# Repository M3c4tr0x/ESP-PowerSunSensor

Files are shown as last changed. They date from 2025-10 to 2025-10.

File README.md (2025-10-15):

# Irradiance and Theoretical Power Calculation Board for Photovoltaic Systems

This board is designed to measure irradiance using a small solar panel and to estimate the theoretical power output of a photovoltaic installation using an NTC temperature sensor placed on one of the panels.

The system is intended for photovoltaic setups that **cannot inject electricity into the grid** — whether on-grid or off-grid. It helps determine real-time production capacity and supports better energy management and self-consumption.

## Features

- **Irradiance Measurement**  
  A miniature solar panel captures real-time irradiance levels.

- **Theoretical Power Estimation**  
  An NTC sensor measures panel temperature to calculate expected power output under current conditions.

- **No-Grid-Injection Systems**  
  Ideal for photovoltaic installations restricted from injecting power into the grid.

- **Performance Monitoring**  
  Provides data to evaluate the system's efficiency and optimize energy usage.
  
  On the first graphe below, you can see the values of the ESP-PowerSunSensor are shown in blue, and my solar production values in yellow :
  
  Capture d'écran 2025-10-09 132655

  Below is the list of the different data reported by the sensor : 
  
  Capture d'écran 2025-10-15 134230

## Use Cases

- Estimating maximum potential production of a solar installation  
- Monitoring performance over time  
- Supporting system design or troubleshooting  
- Managing loads in self-consumption scenarios

## Required Components

- Miniature solar panel (I personally used the glass solar panel from a solar garden lamp recovered from the recycling center)  
- NTC temperature sensor (attach to one of the main panels) : Any NTC sensor can be used, as long as you adapt the pull-up resistor (R16 on the PCB) value and know the sensor’s B25/50 characteristics, which should be entered into the YAML configuration.
- An ESP-PowerSunSensor PCB wired according to the associated schematic diagram
- Power supply and data interface (USB, Wi-Fi, etc.)

Beta version : 



## 💰 How Much Does It Cost?

This project is designed to be **as low-cost as possible**, using affordable or recycled components.

| Component | Estimated Price (€) | Notes |
|---|---|---|
| Miniature solar panel | 0 – 5 € | Recovered from a solar garden lamp (recycling center, old devices) |
| NTC temperature sensor | 1 – 3 € | Any NTC sensor works 10kR to 100kR (adapt pull-up resistor and B-value in YAML) |
| ESP32-C3-WROOM-02 | 3 – 8 € | |
| ESP-PowerSunSensor PCB | 2 – 5 € | Depending on quantity and supplier (JLCPCB, PCBWay, etc.) |
| Resistors, connectors, etc. | 1 – 2 € | Very cheap, or reusable from old electronics |
| 5V USB power supply | 2 – 5 € | Standard USB charger or reused power source |

### 💡 Total Estimated Cost: **around 10 to 25 €**

> 💬 **Tip**: If you recycle parts (panel, power supply, cables), the full setup can cost **less than 10 €**!

## Installation

1. Connect J2 by strapping it to enable bootloader mode on the ESP32
2. Attach the electronic board to your computer using an USB cable.
3. Disconnect J2 (unstrap it) after enabling bootloader mode
4. Go to your ESP-home server and flash the new device with attached yaml customized for your settings
5. After that, you can remove the USB cable
6. Connect the miniature solar panel to the input for irradiance measurement (J3).
7. Attach the NTC sensor firmly to the back side of one of your main solar panels and connect it on J1 connector.


8. Mount the sensor in same direction of your installation you want to monitor, example (files attached in repo) :





9. You can separate the solar panel and NTC sensor from the electronics PCB. In my case, they are positioned 15 meters apart, and the system works fine. This tip allows for a better Wi-Fi connection by placing the electronics closer to my Wi-Fi access point.
10. Connect the USB cable to the power supply.
11. Enjoy your setup and power monitoring!

## Author

- @M3c4tr0x

## License

[MIT License]

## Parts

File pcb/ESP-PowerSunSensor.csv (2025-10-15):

Reference | Qty | Value | DNP | Exclude from BOM | Exclude from Board | Footprint | Datasheet
C1 | 1 | 220nF |  |  |  | Capacitor_SMD:C_0603_1608Metric_Pad1.08x0.95mm_HandSolder | ~
C2,C3,C5 | 3 | 100nF |  |  |  | Capacitor_SMD:C_0603_1608Metric_Pad1.08x0.95mm_HandSolder | ~
C4,C6,C7 | 3 | 10uF |  |  |  | Capacitor_SMD:C_0603_1608Metric_Pad1.08x0.95mm_HandSolder | ~
D1,D2 | 2 | LED |  |  |  | LED_SMD:LED_0603_1608Metric_Pad1.05x0.95mm_HandSolder | ~
D6 | 1 | BAS516 |  |  |  | Diode_SMD:D_SOD-523 | https://assets.nexperia.com/documents/data-sheet/BAS16_SER.pdf
FID1,FID2,FID3,FID4 | 4 | Fiducial |  | Exclure de la Liste du Matériel |  | MountingHole:MountingHole_3.2mm_M3 | ~
J1,J2 | 2 | Conn_01x02_Pin |  |  |  | Connector_PinHeader_2.54mm:PinHeader_1x02_P2.54mm_Vertical | ~
J3 | 1 | Conn_01x02 |  |  |  | Connector_Phoenix_MSTB:PhoenixContact_MSTBVA_2,5_2-G-5,08_1x02_P5.08mm_Vertical | ~
J4 | 1 | Conn_01x04_Pin |  |  |  | Connector_PinHeader_2.54mm:PinHeader_1x04_P2.54mm_Vertical | ~
J5 | 1 | USB_C_Receptacle_USB2.0_16P |  |  |  | oem_connecteur:GCT_USB4500-03-0-A_REVA1 | https://www.usb.org/sites/default/files/documents/usb_type-c.zip
JP1,JP2 | 2 | SolderJumper_3_Open |  |  |  | Jumper:SolderJumper-3_P2.0mm_Open_TrianglePad1.0x1.5mm_NumberLabels | ~
R1 | 1 | R |  |  |  | Resistor_SMD:R_2512_6332Metric_Pad1.40x3.35mm_HandSolder | ~
R2,R3 | 2 | 10R |  |  |  | Resistor_SMD:R_0603_1608Metric_Pad0.98x0.95mm_HandSolder | ~
R4,R5,R6,R7,R8,R9 | 6 | 10k |  |  |  | Resistor_SMD:R_0603_1608Metric_Pad0.98x0.95mm_HandSolder | ~
R10,R11 | 2 | 0R |  |  |  | Resistor_SMD:R_0603_1608Metric_Pad0.98x0.95mm_HandSolder | ~
R12,R13 | 2 | 1k |  |  |  | Resistor_SMD:R_0603_1608Metric_Pad0.98x0.95mm_HandSolder | ~
R14,R15 | 2 | 5.1k |  |  |  | Resistor_SMD:R_0603_1608Metric_Pad0.98x0.95mm_HandSolder | ~
R16 | 1 | 12k |  |  |  | Resistor_SMD:R_0603_1608Metric_Pad0.98x0.95mm_HandSolder | ~
U1 | 1 | INA228 |  |  |  | Package_SO:VSSOP-10_3x3mm_P0.5mm | https://www.ti.com/lit/ds/symlink/ina228.pdf
U2 | 1 | ESP32-C3-WROOM-02 |  |  |  | RF_Module:ESP32-C3-WROOM-02 | https://www.espressif.com/sites/default/files/documentation/esp32-c3-wroom-02_datasheet_en.pdf
U4 | 1 | NCP1117-3.3_SOT223 |  |  |  | Package_TO_SOT_SMD:SOT-223-3_TabPin2 | http://www.onsemi.com/pub_link/Collateral/NCP1117-D.PDF

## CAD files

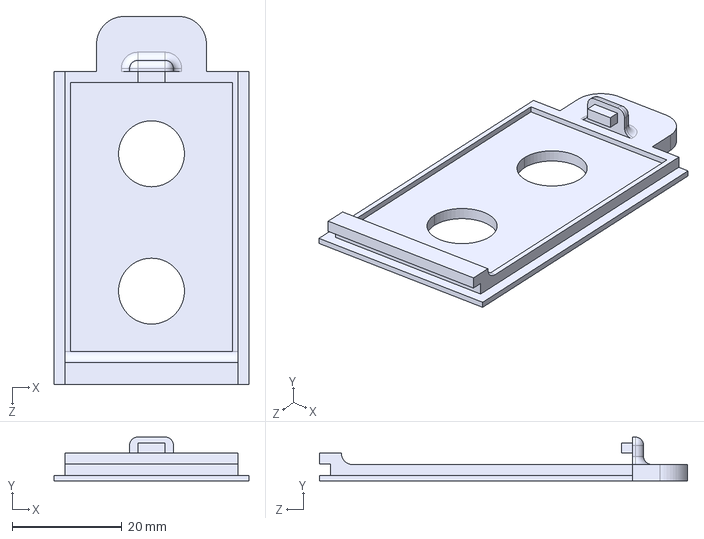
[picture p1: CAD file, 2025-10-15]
case/trappe de maintenance.STEP
35.5 x 8.00 x 67.0 mm

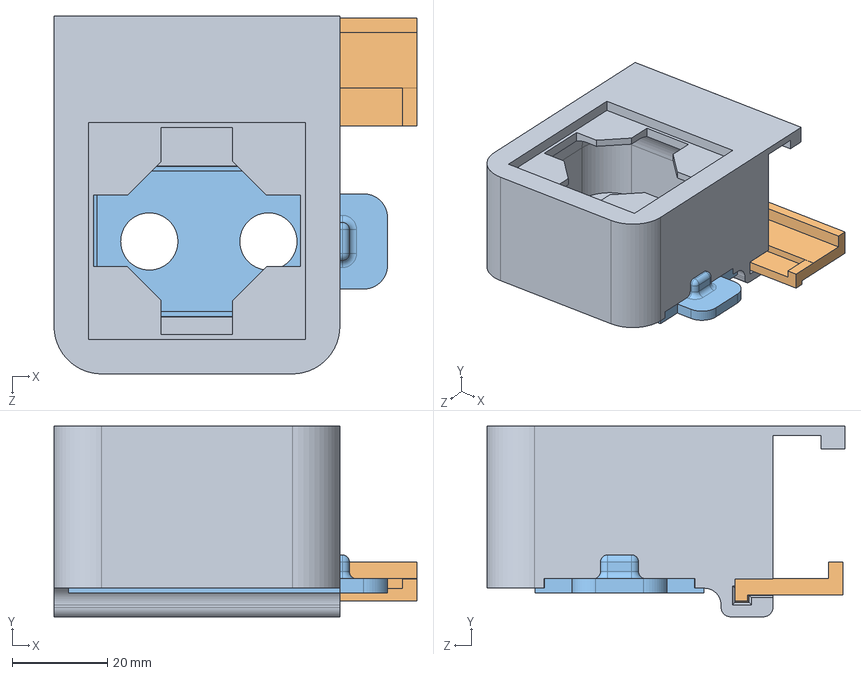
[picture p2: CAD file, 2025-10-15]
case/support capteur PV assemblé.STEP
76.2 x 40.0 x 75.1 mm
support capteur PV
clip support PV
trappe de maintenance

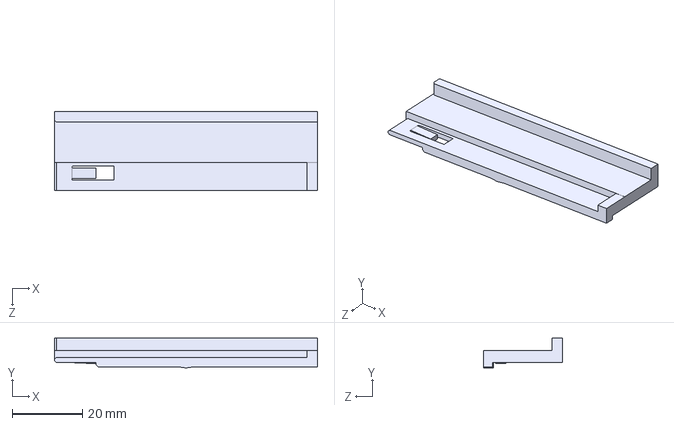
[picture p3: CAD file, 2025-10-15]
case/clip support PV.STEP
75.0 x 8.50 x 22.6 mm

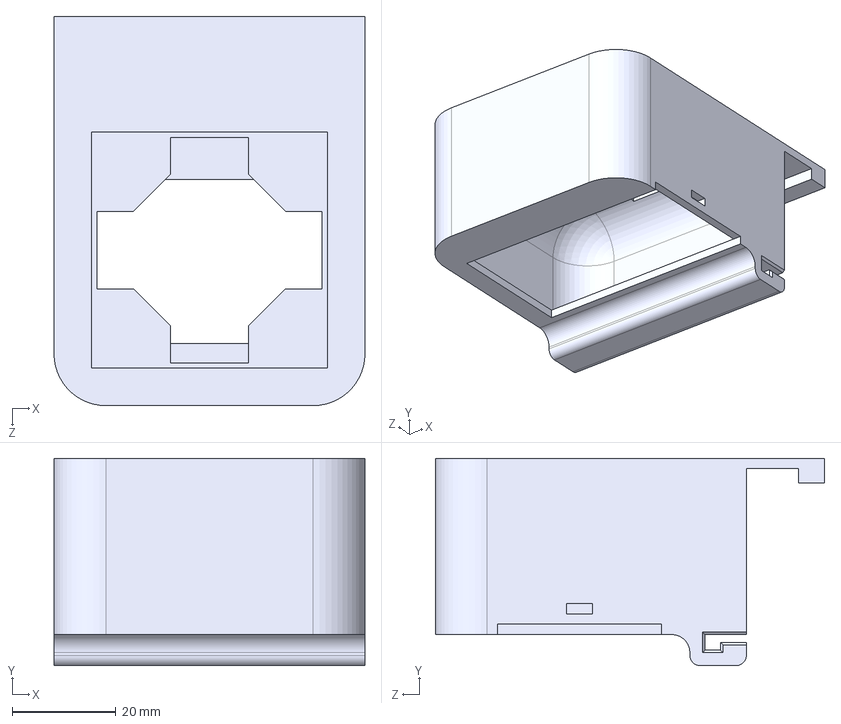
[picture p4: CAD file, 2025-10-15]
case/support capteur PV.STEP
60.0 x 40.0 x 75.1 mm

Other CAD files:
case/clip support PV.3MF
case/clip support PV.SLDPRT
case/support capteur PV assemblé.SLDASM
case/support capteur PV.3MF
case/support capteur PV.SLDPRT
case/trappe de maintenance.3MF
case/trappe de maintenance.SLDPRT

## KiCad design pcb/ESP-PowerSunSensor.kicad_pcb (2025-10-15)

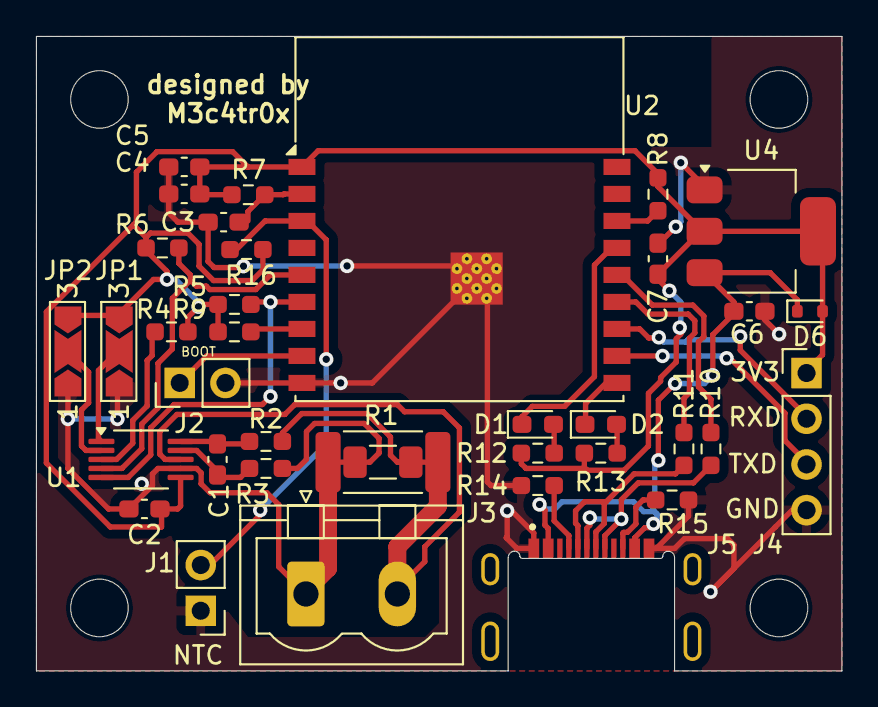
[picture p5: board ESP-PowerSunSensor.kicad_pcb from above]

Board: 2 copper layers, 44.8 x 35.2 mm, 40 parts (0 on the bottom side), 28 nets.

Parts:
C1: 220nF; C_0603_1608Metric_Pad1.08x0.95mm_HandSolder
C2, C3, C5: 100nF; C_0603_1608Metric_Pad1.08x0.95mm_HandSolder
C4, C6, C7: 10uF; C_0603_1608Metric_Pad1.08x0.95mm_HandSolder
D1, D2: LED; LED_0603_1608Metric_Pad1.05x0.95mm_HandSolder
D6: BAS516; D_SOD-523
FID1, FID2, FID3, FID4: Fiducial; MountingHole_3.2mm_M3
J1, J2: Conn_01x02_Pin; PinHeader_1x02_P2.54mm_Vertical
J3: Conn_01x02; PhoenixContact_MSTBVA_2,5_2-G-5,08_1x02_P5.08mm_Vertical
J4: Conn_01x04_Pin; PinHeader_1x04_P2.54mm_Vertical
J5: USB_C_Receptacle_USB2.0_16P; GCT_USB4500-03-0-A_REVA1
JP1, JP2: SolderJumper_3_Open; SolderJumper-3_P2.0mm_Open_TrianglePad1.0x1.5mm_NumberLabels
R1: R; R_2512_6332Metric_Pad1.40x3.35mm_HandSolder
R2, R3: 10R; R_0603_1608Metric_Pad0.98x0.95mm_HandSolder
R4, R5, R6, R7, R8, R9: 10k; R_0603_1608Metric_Pad0.98x0.95mm_HandSolder
R10, R11: 0R; R_0603_1608Metric_Pad0.98x0.95mm_HandSolder
R12, R13, R16: 1k; R_0603_1608Metric_Pad0.98x0.95mm_HandSolder
R14, R15: 5.1k; R_0603_1608Metric_Pad0.98x0.95mm_HandSolder
U1: INA228; VSSOP-10_3x3mm_P0.5mm
U2: ESP32-C3-WROOM-02
U4: NCP1117-3.3_SOT223; SOT-223-3_TabPin2

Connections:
+3V3: C2.1, C4.1, C5.1, C7.1, D6.2 (A), J4.1, JP1.3 (B), JP2.3 (B), R4.1, R5.1, R6.1, R7.1, R8.1, R9.1, R12.1, R13.1, R16.1, U1.6 (VS), U2.1 (3V3), U4.2 (VO)
GND: C2.2, C3.2, C4.2, C5.2, C6.2, C7.2, J1.1, J2.2, J3.1, J4.4, J5.A1 (GND), J5.B1 (GND), JP1.1 (A), JP2.1 (A), R1.2, R3.1, R14.2, R15.2, U1.7 (GND), U2.9 (GND), U2.19 (GND), U4.1 (GND)
unnamed: D1.2 (A), R12.2
unnamed: D1.1 (K), U2.15 (IO3)
unnamed: D2.2 (A), R13.2
unnamed: D2.1 (K), U2.10 (IO10)
unnamed: C6.1, D6.1 (K), J5.A4 (VBUS), J5.B4 (VBUS), U4.3 (VI)
unnamed: J1.2, R16.2, U2.3 (IO4)
unnamed: J2.1, U2.8 (IO9)
unnamed: J3.2, R1.1, R2.1, U1.8 (Vbus)
unnamed: J4.2, U2.12 (IO21/TXD)
unnamed: J4.3, U2.11 (IO20/RXD)
unnamed: J5.A5 (CC1), R14.1
unnamed: J5.B5 (CC2), R15.1
unnamed: JP1.2 (C), U1.1 (A1)
unnamed: JP2.2 (C), U1.2 (A0)
unnamed: R5.2, U1.5 (SCL), U2.6 (IO7)
unnamed: R6.2, U1.4 (SDA), U2.5 (IO6)
unnamed: C1.1, R2.2, U1.10 (Vin+)
unnamed: C1.2, R3.2, U1.9 (Vin-)
unnamed: R4.2, U1.3 (~Alert)
unnamed: C3.1, R7.2, U2.2 (EN)
unnamed: R8.2, U2.16 (IO2)
unnamed: R9.2, U2.7 (IO8)
unnamed: R11.2, U2.13 (IO18)
unnamed: R10.2, U2.14 (IO19)
USB_D+: J5.A6 (D+), J5.B6 (D+), R10.1
USB_D-: J5.A7 (D-), J5.B7 (D-), R11.1

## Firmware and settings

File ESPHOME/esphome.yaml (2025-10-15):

esphome:
  name: esphome-web-3d5070
  friendly_name: ESP-PowerSunSensor
  min_version: 2025.5.0
  name_add_mac_suffix: false

esp32:
  board: esp32-c3-devkitm-1
  framework:
    type: esp-idf

# Enable logging
logger:

# Enable Home Assistant API
api:

ota:
  - platform: esphome

wifi:
  ssid: !secret wifi_ssid
  password: !secret wifi_password
  ap:

web_server:
  port: 80

i2c:
  sda: GPIO06
  scl: GPIO07
  scan: true
  id: bus_a

script:
  - id: blink_led_update
    mode: restart
    then:
      - output.turn_on: led_update
      - delay: 200ms
      - output.turn_off: led_update
      
globals:
  - id: max_inverter_power
    type: float
    restore_value: no
    initial_value: '6400.0'  
    
  - id: conversion_ratio
    type: float
    restore_value: no
    initial_value: '0.07'  # 70mA → 1000 W/m²
    
  - id: pv_surface_area
    type: float
    restore_value: no
    initial_value: '36.0'     # Total PV panel surface in m²

  - id: pv_efficiency
    type: float
    restore_value: no
    initial_value: '0.215'    # PV efficiency (21.5%)
      
  - id: alpha_isc
    type: float
    restore_value: no
    initial_value: '0.0004'   # Temperature coefficient of current (A/A)/K
    
  - id: power_temp_coefficient
    type: float
    restore_value: no
    initial_value: '-0.0030'  # Power temperature coefficient (-0.30 %/K)
    
sensor:
  - platform: ina2xx_i2c
    id: my_charge_sensor
    model: INA228
    address: 0x40
    shunt_resistance: 0.470 ohm
    max_current: 0.15 A
    adc_range: 0
    update_interval: 2s
    current:
      name: "INA228 Current"
      internal: true
      id: ina_current
      on_value:
        then:
          - script.execute: blink_led_update

  - platform: template
    name: "Irradiance"
    id: irradiance_sensor
    unit_of_measurement: "W/m²"
    device_class: illuminance
    accuracy_decimals: 1
    update_interval: 1s
    lambda: |-
      if (isnan(id(ina_current).state)) {
        return NAN;
      }
      return (id(ina_current).state / id(conversion_ratio)) * 1000.0;

  - platform: template
    name: "Irradiance (Temperature Corrected)"
    id: irradiance_temperature_corrected
    unit_of_measurement: "W/m²"
    device_class: illuminance
    accuracy_decimals: 1
    update_interval: 1s
    lambda: |-
      float G = id(ina_current).state;
      float T = id(temperature_ntc).state;
      if (!std::isfinite(G) || G < 0.0 || !std::isfinite(T)) return NAN;
      // temperature correction : alpha_Isc = 0.04 %/K
      float I_corr = G * (1.0 + id(alpha_isc) * (25.0 - T));
      return (I_corr / id(conversion_ratio)) * 1000.0; // conversion A → W/m²

  - platform: template
    name: "Theoretical PV Power at 25°C"
    id: theoretical_pv_power_25C
    unit_of_measurement: "W"
    device_class: power
    accuracy_decimals: 1
    update_interval: 1s
    lambda: |-
      if (isnan(id(irradiance_temperature_corrected).state)) {
        return NAN;
      }
      // Puissance = Irradiance (W/m²) × Surface (m²) × Efficiency
      float power = id(irradiance_temperature_corrected).state * id(pv_surface_area) * id(pv_efficiency);
      return power;

  - platform: adc
    pin: GPIO4
    id: ntc_source
    attenuation: 12db
    update_interval: 1s
    
  - platform: resistance
    sensor: ntc_source
    configuration: DOWNSTREAM
    resistor: 12000
    id: resistance_sensor

  - platform: ntc
    sensor: resistance_sensor
    calibration:
      b_constant: 3977
      reference_temperature: 25°C
      reference_resistance: 10000
    name: "Temperature NTC"
    unit_of_measurement: "°C"
    accuracy_decimals: 1
    id: temperature_ntc

  - platform: template
    name: "PV Power Calculated (Temperature Corrected)"
    id: pv_power_calculated_temperature_corrected
    unit_of_measurement: "W"
    device_class: power
    accuracy_decimals: 1
    update_interval: 1s
    lambda: |-
      if (isnan(id(theoretical_pv_power_25C).state) || isnan(id(temperature_ntc).state)) {
        return NAN;
      }
      // Temperature cellule in °C
      float T = id(temperature_ntc).state;
      // Correction Pmax (–0,30 % / K)
      float correction = 1.0 + (T - 25.0) * id(power_temp_coefficient);
      float power = id(theoretical_pv_power_25C).state * correction;
      // You can clamp the maximum returned value to the maximum output power of your inverter (in my case, it's 6400W)
      return std::min(power, id(max_inverter_power));

status_led:
  pin:
    number: GPIO3
    inverted: false

output:
  - platform: gpio
    pin: GPIO10
    id: led_update

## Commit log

2025-10-15 First version
    [ESP-PowerSunSensor-B_Cu.gbr, ESP-PowerSunSensor-B_Mask.gbr, ESP-PowerSunSensor-B_Paste.gbr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]
2026-10-07 Ajout des exports 3MF du boîtier et nettoyage du dépôt
    - case : exports 3MF (clip support PV, support capteur PV, trappe de maintenance) pour l'impression 3D
    - pcb : suppression du fichier de verrou KiCad commité par erreur
    - pcb : nouvelles règles DRC/ERC ajoutées par KiCad (text_on_edge_cuts, undefined_netclass)
    - .gitignore : exclusion des sauvegardes KiCad (*-backups/) et des verrous (*.lck)
    [clip support PV.3MF, support capteur PV.3MF, trappe de maintenance.3MF]
2026-10-07 Retrait du suivi des fichiers locaux KiCad (fp-info-cache, .kicad_prl)
